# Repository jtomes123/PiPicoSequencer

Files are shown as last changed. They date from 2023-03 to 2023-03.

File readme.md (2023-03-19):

# Pi Pico based Step Sequencer

## Introduction

Goal of this project is to provide a functional step sequencer, that would be relatively portable, easy to use and fully hackable.

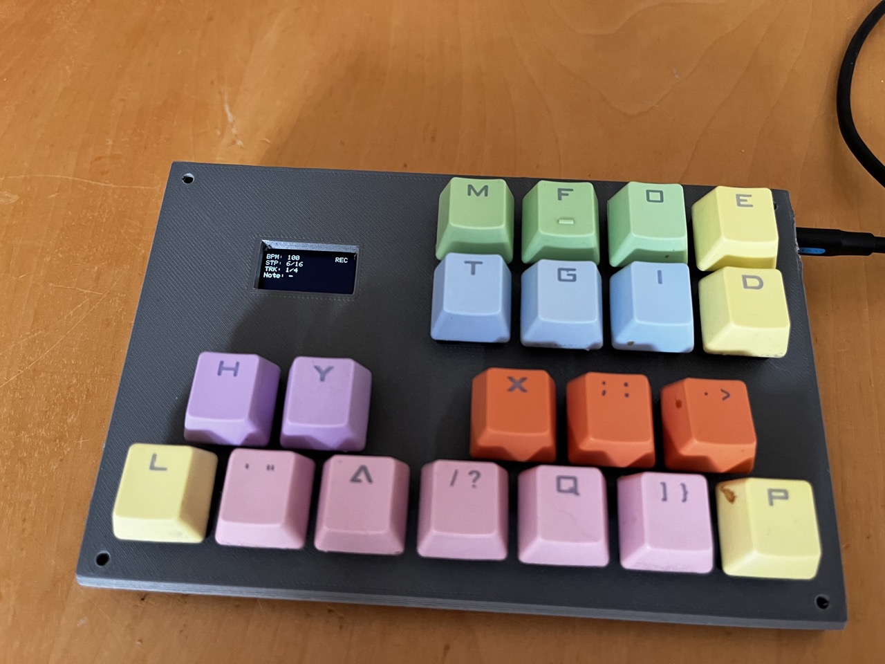
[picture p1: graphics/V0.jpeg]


## Version 0

Version 0 is an experimental prototype with a hand wired keyboard matrix and display, not great but it works pretty well.

### Demo of USB MIDI going to GarageBand on an ipad

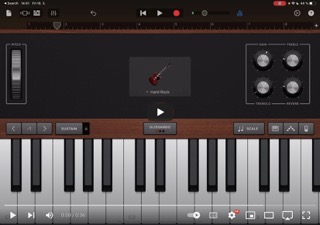
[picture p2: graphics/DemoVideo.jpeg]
Thumbnail (https://www.youtube.com/watch?v=seA91Q_EiBI)


### Hardware

* Raspberry Pi Pico
* 20 keyboard switched
* I2C SSD1306 display
* Midi connector
* Misc
    * Wire
    * Diodes
    * Resistors (10ohm and 33ohm)

#### Schematic

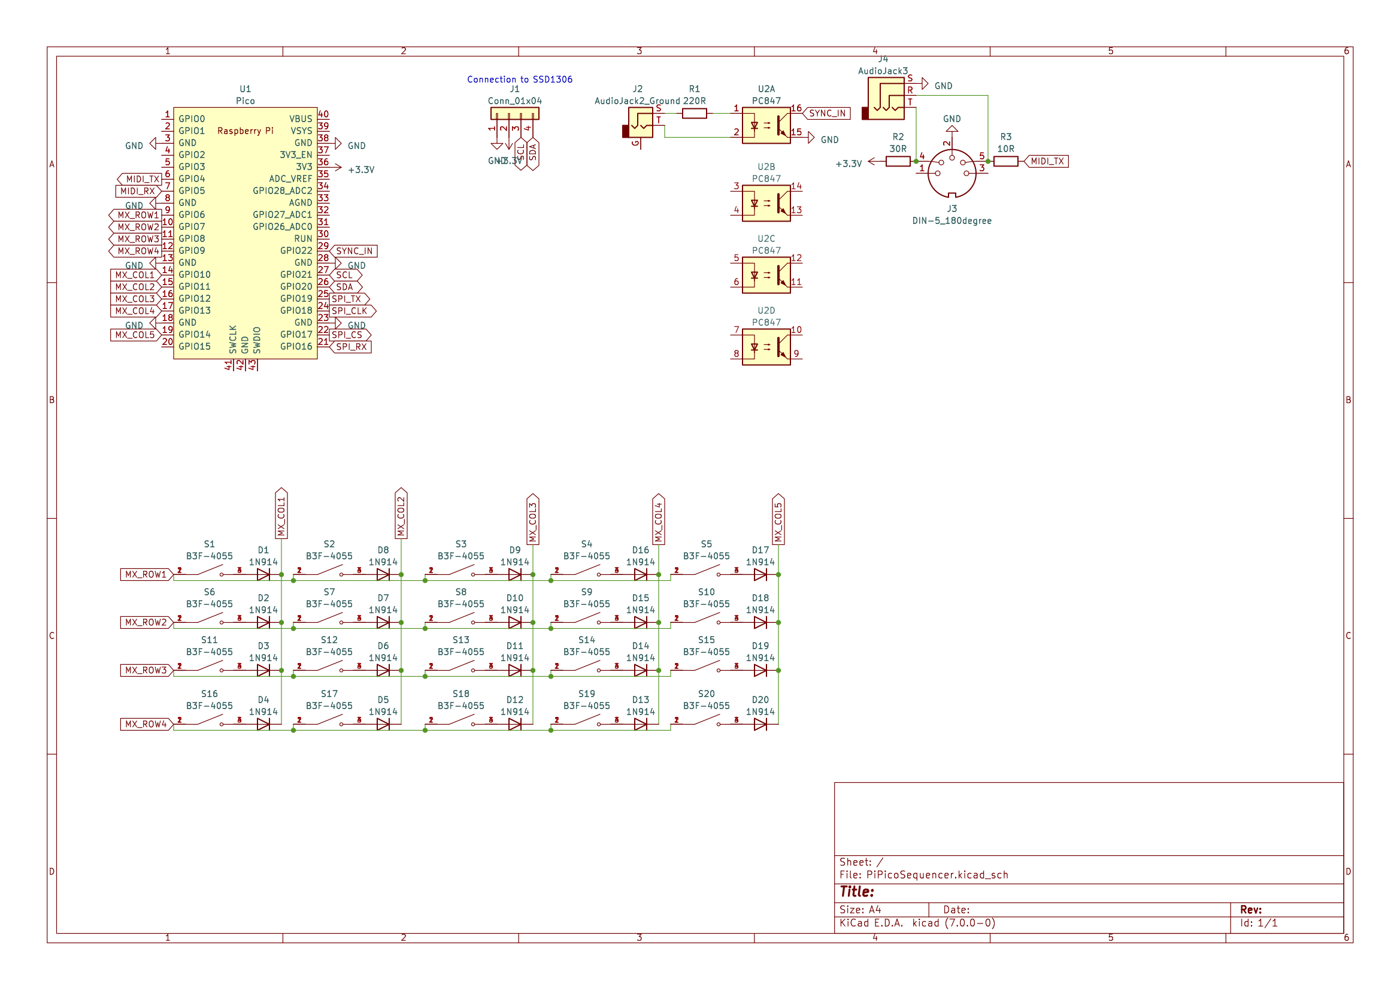
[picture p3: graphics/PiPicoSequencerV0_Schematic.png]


There is an error in the schematic and gate in should have reversed connection to the jack!!!

### Firmware

The newest version of the firmware is src/main_v2.py, I decided to rewrite the firmware to utilize coroutines and improve performance. There was severe performance degradation while writing to the display, so display is now essentially disabled while in play mode and step mode is recommended for editing. The sequencer was tested with E1M1 (also default pattern 1) and it was able to believably reproduce it using usb midi and garageband. Hardware midi was tested with Behringer Model D.

### Controls

#### Modes

##### Play mode

Default mode when the sequencer starts up, the keyboard can be played as a midi instrument and programmed sequences are played. No sequence programming is performed.

##### Record mode

The keyboard programmes notes into the sequence.

##### Step mode

Can be activated in both PLAY and RECORD modes. In play mode, it pauses playback. If activated in record mode, automatic sequence advance and stepping is performed manually.

#### Control layout

There are eight function button numbered from top left 1, 2, 3, 4 on the first rown and 5, 6, 7, 8 on the second row.

() - with modifier 1
[] - with modifier 2

The other keys are one octave of piano keys.

##### Play mode

* 1: Enter or exit record mode, disable step mode
* 2: Enter step mode, next step in step mode
* 3: (Steps per beat)
* 4: Tempo +, (octave +), [midi channel +]
* 5: Modifier 1
* 6: Modifier 2
* 7: RESERVED FOR FUTURE: 5x Tempo +/- 
* 8: Tempo -, (octave -), [midi channel -]

##### Record mode:

* 1: Enter or exit record mode, disable step mode
* 2: Enter step mode, next step in step mode
* 3: Note length - 1/n, (Steps per beat)
* 4: Track +, (octave +), [midi channel +]
* 5: Modifier 1
* 6: Modifier 2
* 7: note mode - one note, double note, triple note
* 8: Track -, (octave -), [midi channel -]

## Version 1.5

Version 1.5 is based on the [RP2040-LCD-1.28](https://www.waveshare.com/wiki/RP2040-LCD-1.28) by waveshare it is an RP2040 based board that is built around a circular lcd screen. There are also additional ports for SYNC, CV+GATE and MIDI right on the pcb in the form of TRS sockets. Most of the parts are or will be surface mount, so it should be mostly JLCPCB assembly friendly.

### PCB Renders

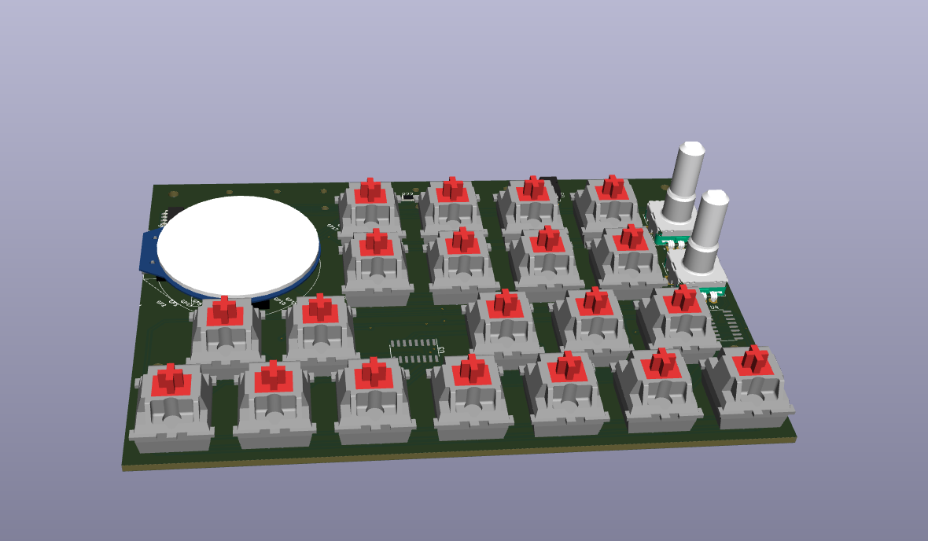
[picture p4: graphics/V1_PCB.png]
PCB Top

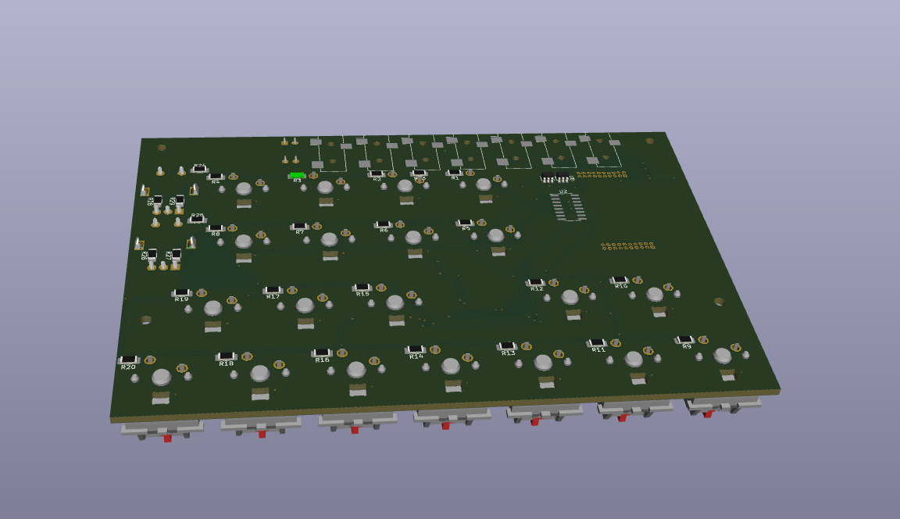
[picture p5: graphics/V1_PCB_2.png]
PCB Bottom


## TODO:
* Improve readme
* Create schematic
* Create control layout scheme that is readable
* Design a PCB
    * Cheaper variant with nice tactile smd buttons
    * Fancy variant with cherry mx buttons
    * A variant with touch keys???
* Provide a way for people to buy a kit
* Provide limited amount of prebuilt kits (I will have to figure out the logistics of this one)
* Update case and model case lid

## Planned additional features:
* CV + Gate out for 1 or 2 tracks
* Sync IN/OUT (Simple enough, hopefully)
* Save/Load
* Track length/count configuration
* Track patterning???
* Port firmware to C or Rust (rust has nice async/await, etc...) using the pico sdk - after final hardware and stable circuitpython firmware
* Different screen
    * Bigger to improve readability
    * Faster to remove the ssd1306 bottleneck
    * [Candidate](https://www.aliexpress.com/item/1005004726017957.html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)

# References

[Cherry mx step model](https://github.com/ConstantinoSchillebeeckx/cherry-mx-switch)

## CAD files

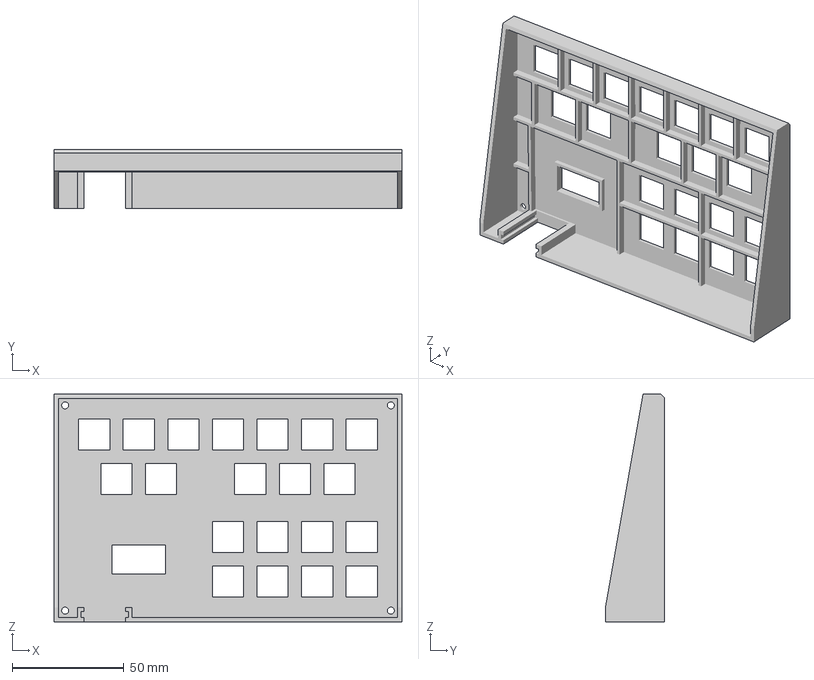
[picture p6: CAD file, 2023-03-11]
models/SequencerCase.3mf
156.0 x 26.5 x 102.0 mm

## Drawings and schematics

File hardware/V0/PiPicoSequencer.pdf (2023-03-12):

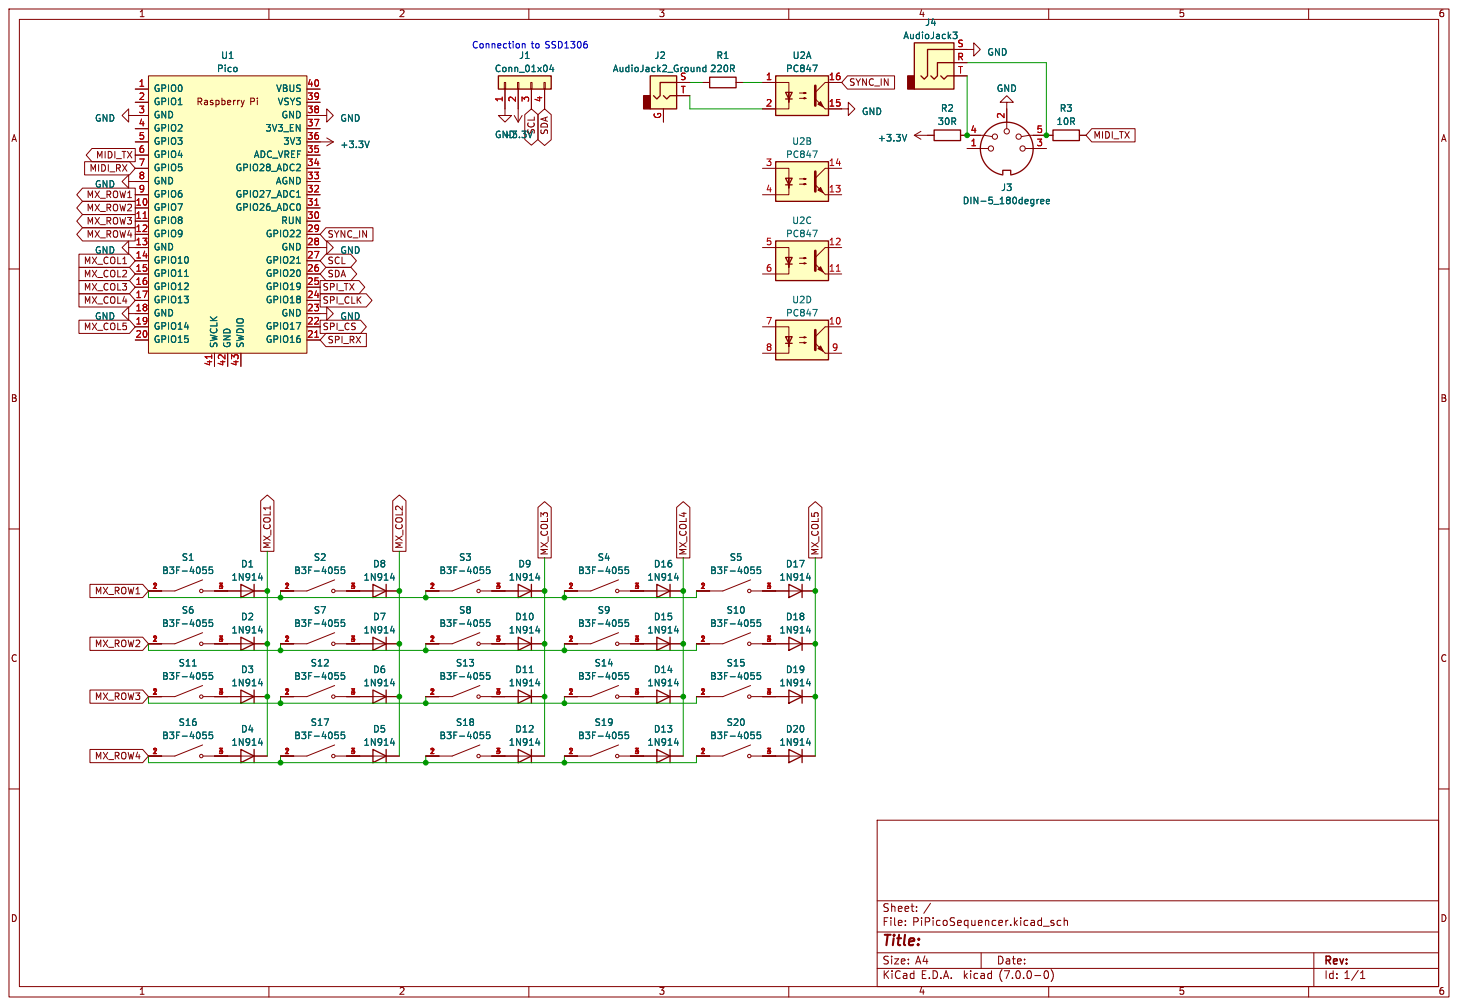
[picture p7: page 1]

Id: 1/1 Title: File: PiPicoSequencer.kicad_sch Sheet: / D19

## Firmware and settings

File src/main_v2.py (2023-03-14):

import usb_midi
import adafruit_ssd1306
import digitalio

import board
import busio as io
import time
import keypad
import asyncio

_ext_sync_pin = digitalio.DigitalInOut(board.GP22)
_ext_sync_pin.direction = digitalio.Direction.INPUT
_ext_sync_pin.pull = digitalio.Pull.UP

t1b1 = ["C", "C#", "D", "D#", "E", "F", "F#", "G", "G#", "A", "A#", "B"]
keymap = dict()
keymap[9] = 0
keymap[4] = 1
keymap[19] = 2
keymap[14] = 3
keymap[18] = 4
keymap[13] = 5
keymap[12] = 6
keymap[17] = 7
keymap[11] = 8
keymap[16] = 9
keymap[10] = 10
keymap[15] = 11
keymap[3] = 12
keymap[2] = 13
keymap[1] = 14
keymap[0] = 15
keymap[8] = 16
keymap[7] = 17
keymap[6] = 18
keymap[5] = 19


def midi2str(midi):
    note = midi[0]
    l = midi[2]
    m = midi[3]
    return "{} ({}) M{}".format(t1b1[note % 12] + str(int(note / 12) - 2), 2 ** l, m)


def nt(num):
    return (num, 127, 0, 0)


def e1m1():
    return [nt(28), nt(40), nt(52), nt(28), nt(40), nt(50), nt(28), nt(40), nt(48), nt(28), nt(40), nt(46), nt(28), nt(40), nt(47), nt(48)]


def prepare_but(pin):
    p = digitalio.DigitalInOut(pin)
    p.direction = digitalio.Direction.INPUT
    p.pull = digitalio.Pull.UP
    return lambda: p.value


async def wait(ms):
    await asyncio.sleep_ms(int(ms))


async def wait_for_trigger(interval_ms=1):
    global _ext_sync_pin, _step_mode
    previous_value = _ext_sync_pin.value
    while True:
        current_value = _ext_sync_pin.value
        if (not current_value and previous_value) or not _step_mode:
            print("Ext trigger...")
            break
        await asyncio.sleep_ms(interval_ms)
        previous_value = current_value


keyboard = keypad.KeyMatrix(row_pins=(board.GP6, board.GP7, board.GP8, board.GP9), column_pins=(
    board.GP10, board.GP11, board.GP12, board.GP13, board.GP14), columns_to_anodes=False, interval=0.02)

i2c = io.I2C(board.GP21, board.GP20)
oled = adafruit_ssd1306.SSD1306_I2C(128, 64, i2c, addr=0x3C)
uart_midi = io.UART(board.GP4, board.GP5, baudrate=32250)
usb_midi_out = usb_midi.ports[1]

oled.fill(0)
oled.show()

_tempo = 120
_steps = 16
_step = 0
_step_progress = 0
_notes_per_beat = 2

_track = 0
_tracks = 4
_octave = 5

_last_step_time = 0
_full_velocity = True
_recording = False
_step_mode = False
_redraw = True

_data = []
_channels = []

for i in range(_tracks):
    _data.append([])
    _channels.append(0)
    for j in range(_steps):
        _data[i].append((-1, 0, 0, 0))

_data[0] = e1m1()
print(_data)


def reset_track(t):
    for j in range(_steps):
        _data[t][j] = ((-1, 0, 0, 0))


midilock = asyncio.Lock()
datalock = asyncio.Lock()


def _send_note_on(note, vel, ch=0):
    note_on_status = (0x90 | (ch))
    msg = bytearray([note_on_status, note, vel])
    uart_midi.write(msg)
    usb_midi_out.write(msg)


def _send_note_off(note, ch=0):
    note_off_status = (0x80 | (ch))
    msg = bytearray([note_off_status, note, 0])
    uart_midi.write(msg)
    usb_midi_out.write(msg)


async def send_note_on(note, vel, ch=0):
    note_on_status = (0x90 | (ch))
    msg = bytearray([note_on_status, note, vel])
    async with midilock:
        uart_midi.write(msg)
        usb_midi_out.write(msg)


async def send_note_off(note, ch=0):
    note_off_status = (0x80 | (ch))
    msg = bytearray([note_off_status, note, 0])
    async with midilock:
        uart_midi.write(msg)
        usb_midi_out.write(msg)


async def send_note(note, vel, duration, ch=0):
    await send_note_on(note, vel, ch)
    await asyncio.sleep_ms(duration)
    await send_note_off(note, ch)


async def send_note_triplet(note, vel, duration, ch=0):
    await send_note_on(note, vel, ch)
    await asyncio.sleep_ms(int(duration / 3 * 0.9))
    await send_note_off(note, ch)
    await asyncio.sleep_ms(int(duration * 0.1))
    await send_note_on(note, vel, ch)
    await asyncio.sleep_ms(int(duration / 3 * 0.9))
    await send_note_off(note, ch)
    await asyncio.sleep_ms(int(duration * 0.1))
    await send_note_on(note, vel, ch)
    await asyncio.sleep_ms(int(duration / 3 * 0.9))
    await send_note_off(note, ch)
    await asyncio.sleep_ms(int(duration * 0.1))


async def send_note_doublet(note, vel, duration, ch=0):
    await send_note_on(note, vel, ch)
    await asyncio.sleep_ms(int(duration / 2 * 0.9))
    await send_note_off(note, ch)
    await asyncio.sleep_ms(int(duration * 0.1))
    await send_note_on(note, vel, ch)
    await asyncio.sleep_ms(int(duration / 2 * 0.9))
    await send_note_off(note, ch)


async def all_notes_off():
    tasks = []
    for i in range(_tracks):
        for j in range(_steps):
            if not _data[i][j][0] == -1:
                tasks.append(send_note_off(_data[i][j][0], _channels[i]))
    await asyncio.gather(*tasks)


async def get_display_data():
    async with datalock:
        return (_tempo, _octave, _step, _steps, _track, _tracks, _recording, _step_mode, _channels[_track], _data[_track][_step], _notes_per_beat, _redraw)


async def get_application_data():
    async with datalock:
        return (_tempo, _octave, _step, _steps, _track, _tracks, _recording, _step_mode, _channels[_track], _notes_per_beat)


async def update_application_data(tempo, octave, recording, step_mode, track, channel, notes_per_beat):
    global _tempo, _octave, _step_mode, _track, _recording, _channels, _notes_per_beat
    async with datalock:
        _tempo = tempo
        _octave = octave
        _step_mode = step_mode
        _track = track
        _channels[track] = channel
        _notes_per_beat = notes_per_beat
        _recording = recording


async def get_step_data(track, step):
    global _data
    async with datalock:
        return _data[track][step]


async def set_step_data(track, step, step_data):
    global _data
    async with datalock:
        _data[track][step] = step_data


async def next_step():
    global _step, _steps
    async with datalock:
        _step += 1
        if _step >= _steps:
            _step -= _steps


async def update_display():
    global _redraw
    while True:
        tempo, octave, step, steps, track, tracks, recording, step_mode, current_channel, step_data, notes_per_beat, redraw = await get_display_data()
        if recording:
            oled.fill(0)
            oled.text("BPM: {} NPB: {}".format(
                tempo, 2 ** notes_per_beat), 0, 0, 1)
            oled.text("OCT: {}".format(octave), 0, 10, 1)
            oled.text("STP: {}/{}".format(step + 1, steps), 0, 20, 1)
            oled.text("TRK: {}/{} (CH{})".format(track + 1,
                                                 tracks, current_channel + 1), 0, 30, 1)
            if step_data[0] == -1:
                oled.text("Note: -", 0, 40, 1)
            else:
                oled.text("Note: {}".format(midi2str(step_data)), 0, 40, 1)
            if recording:
                oled.text("REC", 100, 0, 1)
            if step_mode:
                oled.text("ST", 100, 10, 1)
            oled.show()
            await asyncio.sleep_ms(100)
        elif redraw:
            oled.fill(0)
            oled.text("BPM: {} NPB: {}".format(
                tempo, 2 ** notes_per_beat), 0, 0, 1)
            oled.text("PLA", 100, 0, 1)
            if step_mode:
                oled.text("ST", 100, 10, 1)
            oled.show()
            _redraw = False
            await asyncio.sleep_ms(100)
        else:
            await asyncio.sleep_ms(100)


async def handle_input():
    modifier1_pressed = False
    modifier2_pressed = False
    global _redraw
    while True:
        tempo, octave, step, steps, track, tracks, recording, step_mode, current_channel, notes_per_beat = await get_application_data()
        while True:
            e = keyboard.events.get()
            if e == None:
                break

            key = keymap[e.key_number]

            if key < 12:
                if e.pressed:
                    await send_note_on(key + octave * 12, 127)

                    if recording:
                        await set_step_data(track, step, (key + octave * 12, 127, 0, 0))
                else:
                    await send_note_off(key + octave * 12)
                    pass

            elif e.pressed:
                if not recording:
                    _redraw = True

                if key == 12:
                    if modifier1_pressed:
                        reset_track(track)
                    else:
                        if not step_mode:
                            recording = not recording
                        else:
                            step_mode = False
                elif key == 13:
                    if not step_mode:
                        step_mode = True
                    else:
                        await next_step()
                elif key == 14:
                    if modifier1_pressed:
                        notes_per_beat += 1
                        if notes_per_beat > 4:
                            notes_per_beat = 0
                    else:
                        if recording:
                            n, v, l, m = await get_step_data(track, step)
                            l += 1
                            if l > 4:
                                l = 0

                            await set_step_data(track, step, (n, v, l, m))
                elif key == 15:
                    if modifier1_pressed:
                        octave += 1
                    elif modifier2_pressed:
                        current_channel += 1
                    elif not recording:
                        tempo += 1
                    else:
                        track += 1
                elif key == 16:
                    modifier1_pressed = True
                elif key == 17:
                    modifier2_pressed = True
                elif key == 18:
                    if recording:
                        n, v, l, m = await get_step_data(track, step)
                        m += 1
                        if m > 2:
                            m = 0

                        await set_step_data(track, step, (n, v, l, m))
                elif key == 19:
                    if modifier1_pressed:
                        octave -= 1
                    elif modifier2_pressed:
                        current_channel -= 1
                    elif not recording:
                        tempo -= 1
                    else:
                        track -= 1

                if key == 15 or key == 19:
                    if modifier1_pressed:
                        if octave < 0:
                            octave = 9
                        elif octave > 9:
                            octave = 0
                    elif modifier2_pressed:
                        if current_channel < 0:
                            current_channel = 15
                        elif current_channel > 15:
                            current_channel = 0
                    elif not recording:
                        if tempo < 0:
                            tempo = 0
                        elif tempo > 240:
                            tempo = 240
                    else:
                        if track < 0:
                            track = tracks - 1
                        elif track >= tracks:
                            track = 0
            elif e.released:
                if key == 16:
                    modifier1_pressed = False
                if key == 17:
                    modifier2_pressed = False

        await update_application_data(tempo, octave, recording, step_mode, track, current_channel, notes_per_beat)
        await asyncio.sleep_ms(10)


async def sequencer_routine():
    while True:
        tempo, octave, step, steps, track, tracks, recording, step_mode, current_channel, notes_per_beat = await get_application_data()
        tasks = []

        if recording:
            await asyncio.sleep_ms(33)
            continue

        target_step_time = 60000 // tempo // (2 ** notes_per_beat)

        for i in range(tracks):
            step_data = await get_step_data(i, step)
            if not step_data[0] == -1:
                if step_data[3] == 1:
                    tasks.append(send_note_doublet(step_data[0], step_data[1], int(
                        target_step_time / (2 ** step_data[2]))))
                elif step_data[3] == 2:
                    tasks.append(send_note_triplet(step_data[0], step_data[1], int(
                        target_step_time / (2 ** step_data[2]))))
                else:
                    tasks.append(send_note(step_data[0], step_data[1], int(
                        target_step_time / (2 ** step_data[2]))))

        await next_step()
        if not step_mode:
            tasks.append(wait(target_step_time))
        else:
            tasks.append(wait_for_trigger())
        await asyncio.gather(*tasks)


async def main():
    input_task = asyncio.create_task(handle_input())
    display_task = asyncio.create_task(update_display())
    sequencer_task = asyncio.create_task(sequencer_routine())

    await asyncio.gather(sequencer_task, display_task, input_task)

asyncio.run(main())

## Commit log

2023-03-07 added long and short notes
    [main.py]
2023-03-11 Reworked code to use coroutines
    [main_v2.py]
2023-03-11 Updated repo
    [SequencerCase.3mf]
2023-03-12 Added Schematic
2023-03-14 Added a schematic to the readme
2023-03-19 Added v1.5 PCB
